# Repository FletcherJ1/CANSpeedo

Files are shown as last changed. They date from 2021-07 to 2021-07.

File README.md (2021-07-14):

# OBD Digital Speedometer
This project sparked from not having a digital speed readout on the dashboard of my car (Alfa Romeo Giulietta) when driving in 'Normal' and 'Dynamic' mode. This uses the OBD-II port to read the vehicle speed and then print the speed onto the radio message. This radio message is sent from the radio module to the dashboard and requires the 'Radio Repetition' setting in the dashboard to be enabled for the message to be displayed. This message is sent only when the car is on and is sent at a 2hz rate.

The end result of this is shown below while I was testing the display output:
<p align="center">
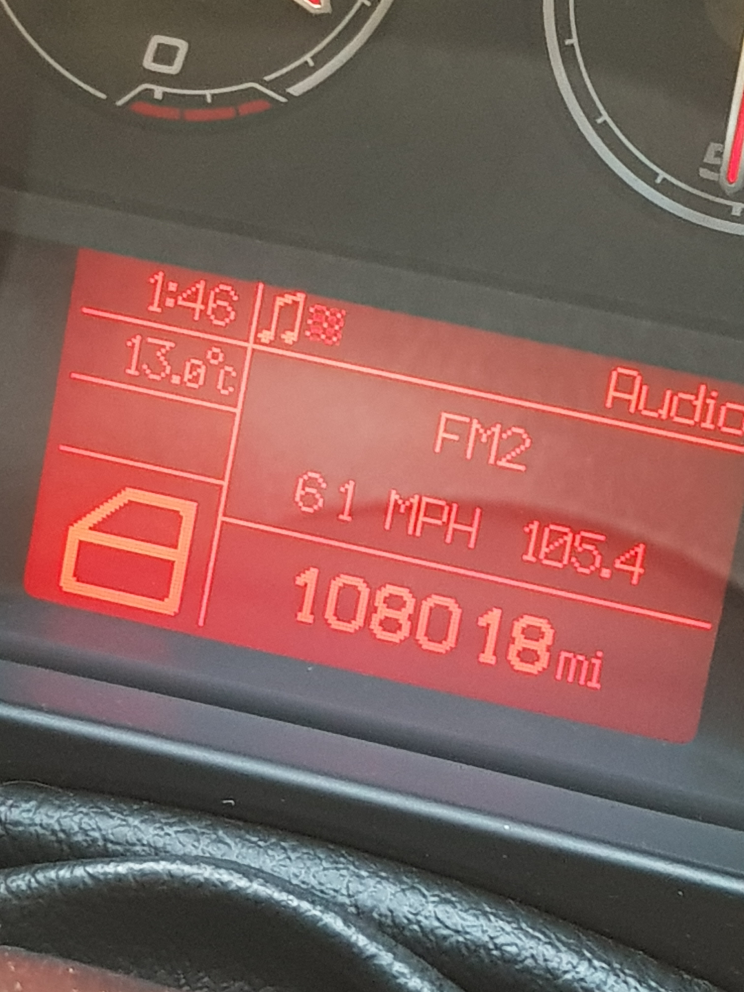
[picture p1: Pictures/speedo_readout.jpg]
    
</p>

## Vehicle information
The CAN network used is a 50Kbps network and is defined as the CAN-B network on the car (pins 1 and 9 on the OBD-2 port).

The car it has been tested on has 16" wheels and is a 2011 model. I'm not sure if the wheel diameter affects the speed value provided by CAN so the variable `SPEED_DIVIDER_MPH` might need to be changed to suit other vehicles and wheel diameters.

## Hardware
The hardware used is centered around an ATmega16M1 because it has an in-built CAN controller and works with the Arduino framework. It also helps keep the PCB as small as possible and keeps components count down.

There is a power switch for powering via either the car through the OBD port or via the ICSP header. This isn't really needed but added to make software development slightly easier.

The PCB is designed using Kicad 5.99 and is made to fit an [OBD-2 case](https://www.ebay.co.uk/itm/153652371926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) found on eBay.

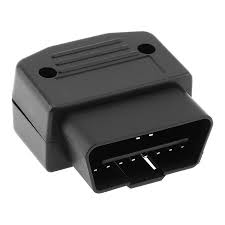
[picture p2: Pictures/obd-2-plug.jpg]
OBD-2 Plug Picture


The PCB is a 4 layer design because it didn't cost any more than a 2 layer design from JLCPCB.
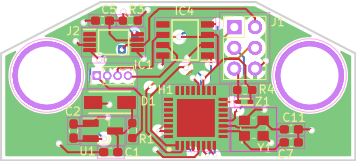
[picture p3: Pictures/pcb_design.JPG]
PCB Design

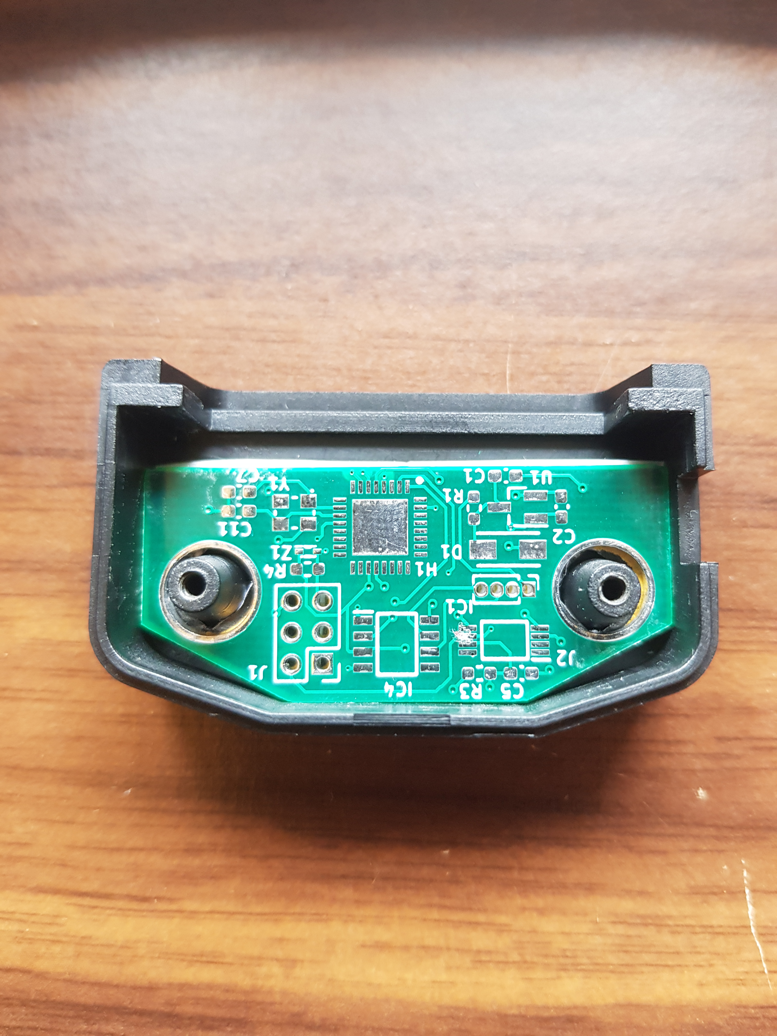
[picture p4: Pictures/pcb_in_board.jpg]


This fits in the car and still allows for the diagnostic panel to fit over the plug when it is plugged in.

## Data dumps
I've also included some data dumps (under the /Dumps folder) containing can information when the car is in various states. Feel free to use this information as desired to decode additional parts of the cars CAN data.

I also included a file in the dumps with additional information I found and some more decoded CAN messages. This might be confusing to read through but should give some ideas.

I found plotting the data with graphs, I used Flow CSV Viewer, quite helpful to find multi-byte variables as well as what the variable may represent based on how the data changes.

## Libraries Used
- [ATMegaxxM1-C1 Arduino IDE Support](https://github.com/thomasonw/ATmegaxxM1-C1)
- [ATMegaxxM1-C1 CAN Library](https://github.com/thomasonw/avr_can)

## Credits
- [FIAT Character Map](https://gist.github.com/fmntf/c4b2744bad3908ef10fc9a5d377f2823)

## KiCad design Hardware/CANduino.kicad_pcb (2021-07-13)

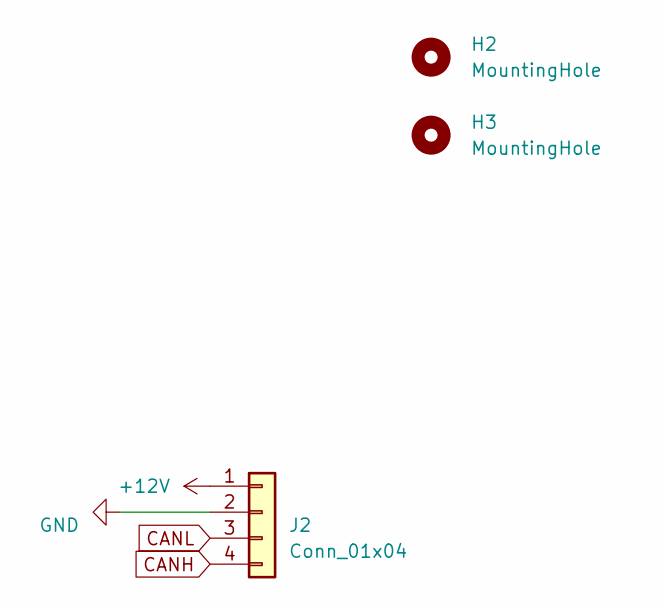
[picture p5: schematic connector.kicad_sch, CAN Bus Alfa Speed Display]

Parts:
H2, H3: MountingHole; MountingHole_6mm_Pad
J2: Conn_01x04; PinHeader_1x04_P1.27mm_Vertical

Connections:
+12V: J2.1; also elsewhere on the board
CANH: J2.4; also elsewhere on the board
CANL: J2.3; also elsewhere on the board
GND: J2.2; also elsewhere on the board

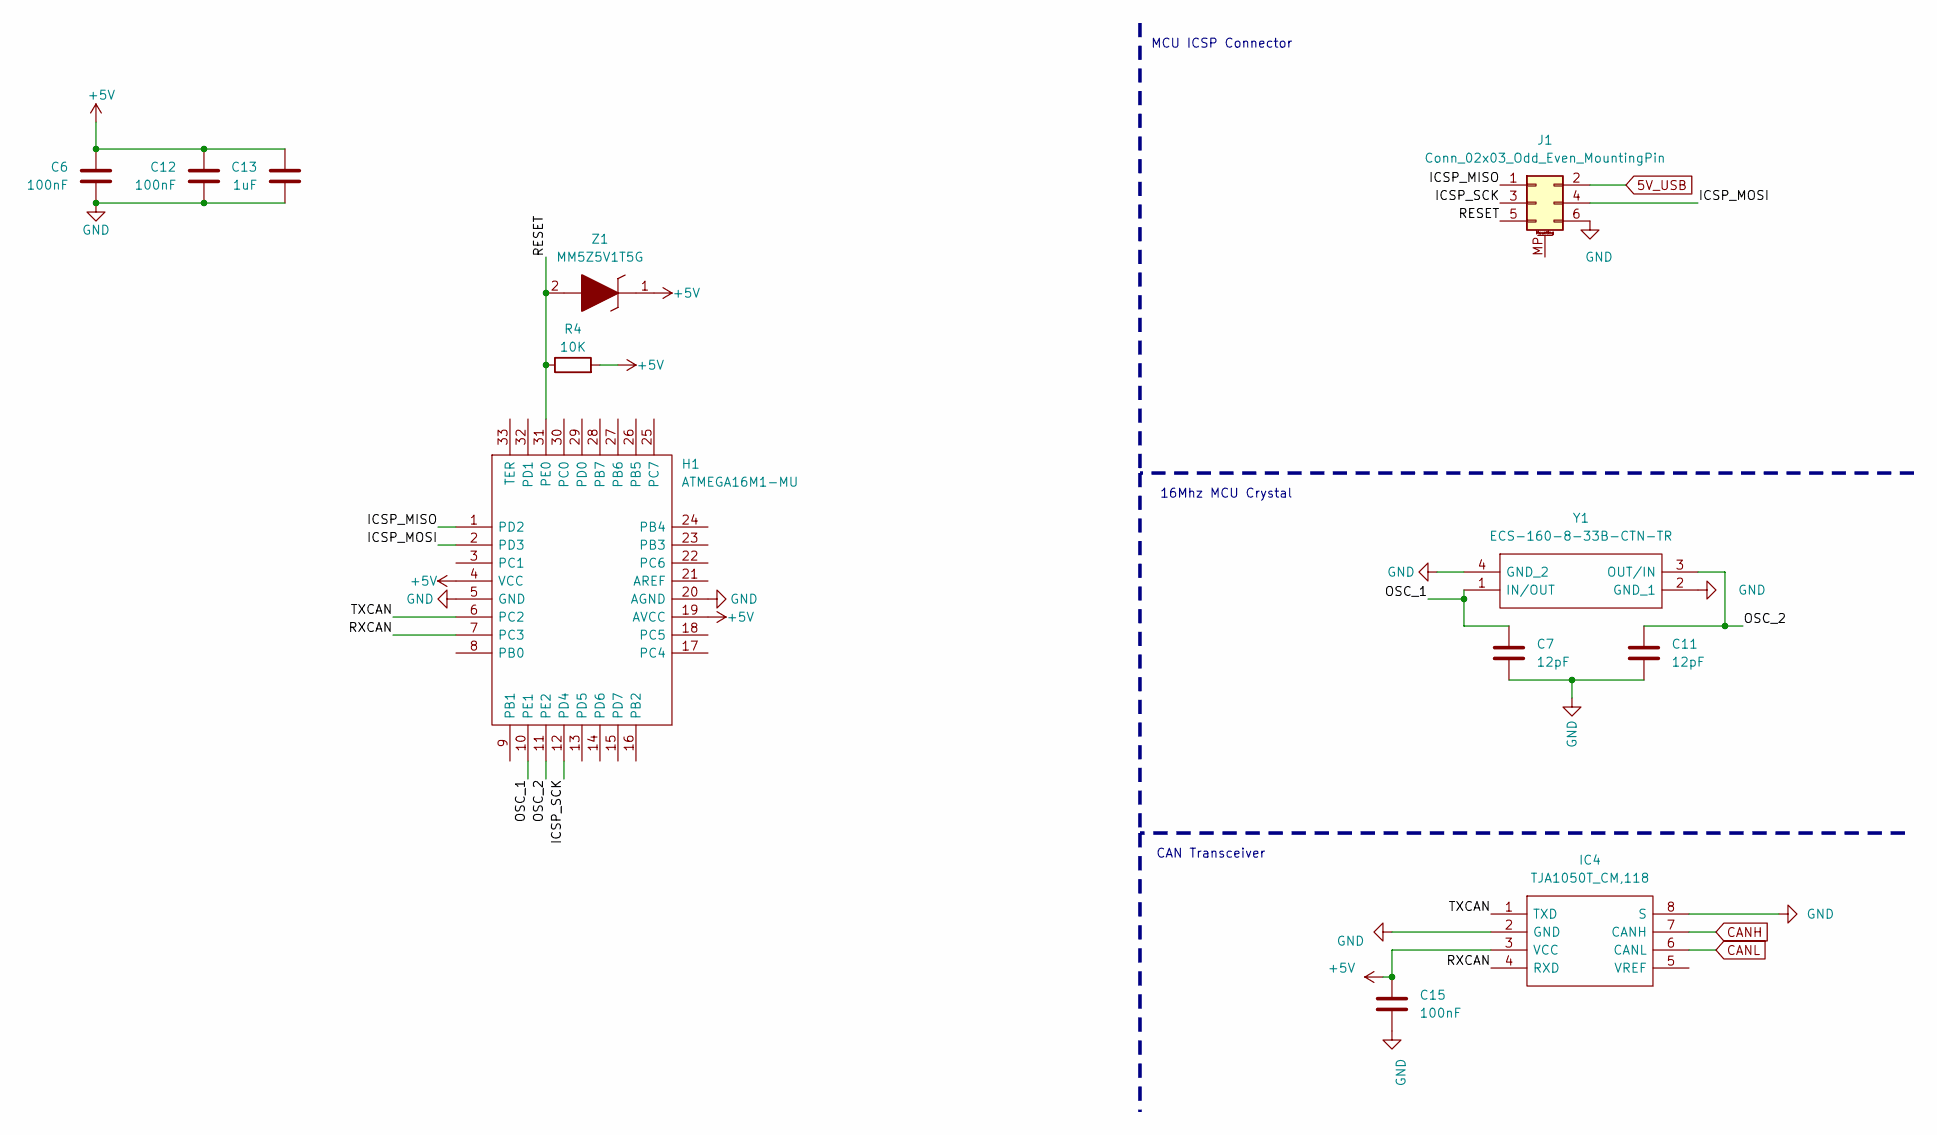
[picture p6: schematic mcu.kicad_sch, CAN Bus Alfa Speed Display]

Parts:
C6, C12, C15: 100nF; C_0603_1608Metric_Pad1.08x0.95mm_HandSolder
C7, C11: 12pF; C_0603_1608Metric_Pad1.08x0.95mm_HandSolder
C13: 1uF; C_0603_1608Metric_Pad1.08x0.95mm_HandSolder
H1: ATMEGA16M1-MU; QFN65P700X700X100-33N; Mouser Part Number 556-ATMEGA16M1-MU
IC4: TJA1050T_CM,118; SOIC127P600X175-8N; Mouser Part Number 771-TJA1050T/CM118
J1: Conn_02x03_Odd_Even_MountingPin; PinHeader_2x03_P2.54mm_Vertical
R4: 10K; R_0603_1608Metric_Pad0.98x0.95mm_HandSolder
Y1: ECS-160-8-33B-CTN-TR; ECS160833BCTNTR; Mouser Part Number 520-ECS160833BCTN-TR
Z1: MM5Z5V1T5G; SODFL1608X70N; Mouser Part Number 863-MM5Z5V1T5G

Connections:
5V_USB: J1.2; also elsewhere on the board
+5V: C6.2, C12.2, C13.2, C15.1, H1.4 (VCC), H1.19 (AVCC), IC4.3 (VCC), R4.2, Z1.1; also elsewhere on the board
/mcu/ICSP_MISO: H1.1 (PD2), J1.1
/mcu/ICSP_MOSI: H1.2 (PD3), J1.4
/mcu/ICSP_SCK: H1.12 (PD4), J1.3
/mcu/OSC_1: C7.1, H1.10 (PE1), Y1.1 (IN/OUT)
/mcu/OSC_2: C11.1, H1.11 (PE2), Y1.3 (OUT/IN)
/mcu/RESET: H1.31 (PE0), J1.5, R4.1, Z1.2
/mcu/RXCAN: H1.7 (PC3), IC4.4 (RXD)
/mcu/TXCAN: H1.6 (PC2), IC4.1 (TXD)
CANH: IC4.7 (CANH); also elsewhere on the board
CANL: IC4.6 (CANL); also elsewhere on the board
GND: C6.1, C7.2, C11.2, C12.1, C13.1, C15.2, H1.5 (GND), H1.20 (AGND), IC4.2 (GND), IC4.8 (S), J1.6, Y1.2 (GND_1), Y1.4 (GND_2); also elsewhere on the board

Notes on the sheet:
CAN Transceiver
MCU ICSP Connector
16Mhz MCU Crystal

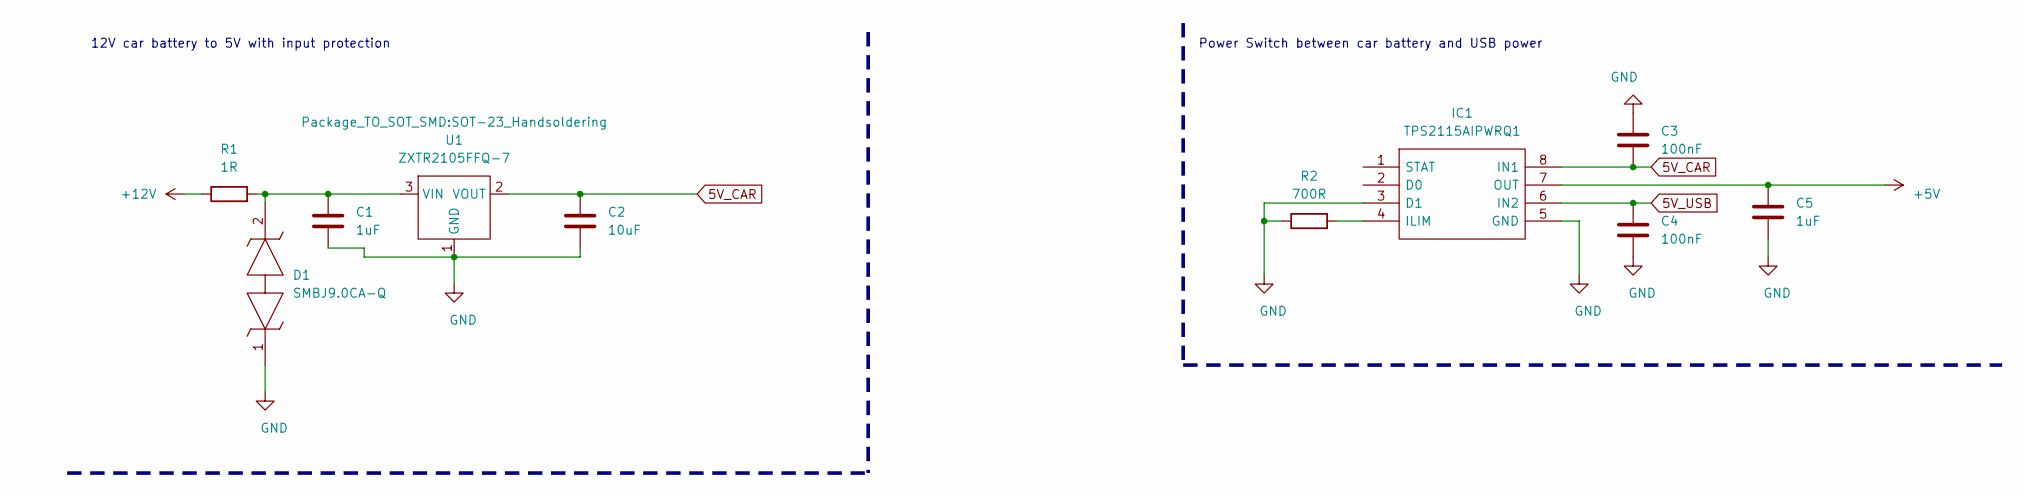
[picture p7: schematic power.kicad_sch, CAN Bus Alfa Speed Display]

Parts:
C1, C5: 1uF; C_0603_1608Metric_Pad1.08x0.95mm_HandSolder
C2: 10uF; C_0603_1608Metric_Pad1.08x0.95mm_HandSolder
C3, C4: 100nF; C_0603_1608Metric_Pad1.08x0.95mm_HandSolder
D1: SMBJ9.0CA-Q; DIONM5127X229N; Mouser Part Number 652-SMBJ9.0CA-Q
IC1: TPS2115AIPWRQ1; SOP65P640X120-8N; Mouser Part Number 595-TPS2115AIPWRQ1
R1: 1R; R_0603_1608Metric_Pad0.98x0.95mm_HandSolder
R2: 700R; R_0603_1608Metric_Pad0.98x0.95mm_HandSolder
U1: ZXTR2105FFQ-7; SOT-23_Handsoldering

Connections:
5V_CAR: C2.1, C3.2, IC1.8 (IN1), U1.2 (VOUT)
5V_USB: C4.1, IC1.6 (IN2); also elsewhere on the board
+5V: C5.1, IC1.7 (OUT); also elsewhere on the board
+12V: R1.1; also elsewhere on the board
GND: C1.2, C2.2, C3.1, C4.2, C5.2, D1.1, IC1.3 (D1), IC1.5 (GND), R2.1, U1.1 (GND); also elsewhere on the board
unnamed: C1.1, D1.2, R1.2, U1.3 (VIN)
unnamed: IC1.4 (ILIM), R2.2

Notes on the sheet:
12V car battery to 5V with input protection
Power Switch between car battery and USB power

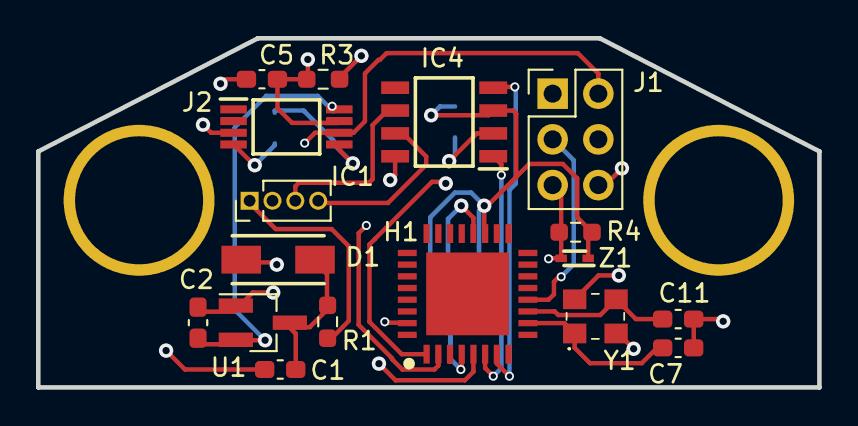
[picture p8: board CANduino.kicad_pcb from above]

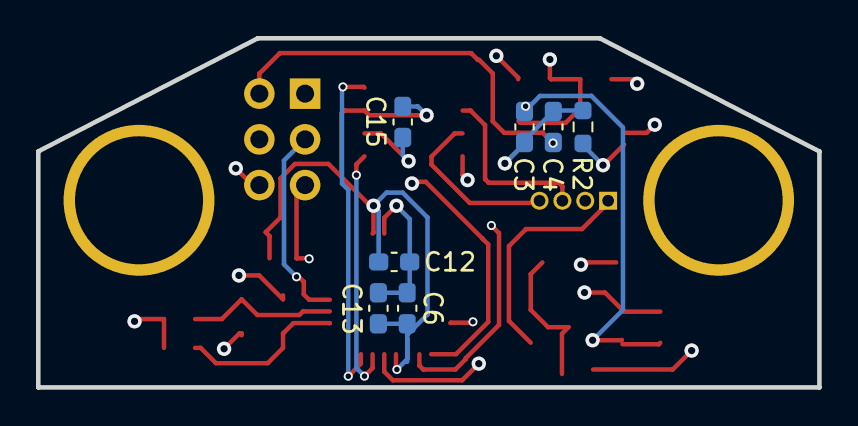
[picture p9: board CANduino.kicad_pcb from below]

Board: 4 copper layers, 43.4 x 19.4 mm, 26 parts (7 on the bottom side), 17 nets.

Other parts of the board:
R3: 50R; R_0603_1608Metric_Pad0.98x0.95mm_HandSolder

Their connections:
+5V: R3.1; also elsewhere on the board
GND: R3.2; also elsewhere on the board

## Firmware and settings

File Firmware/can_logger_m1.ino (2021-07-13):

#include <avr_can.h>
#include <avr/sleep.h>
#include <avr/power.h>

/*
 * Application: Alfa Romeo Giulietta OBD Dash Speedo
 * 
 * 
 * Description:
 *  Attaches to OBD-2 port and overwrites radio station name with speed in MPH at 2Hz rate.
 *  Requires 'Radio Repetition' to be ON in dashboard settings for this to work correctly.
 *  Dashboard update speed is slow enough that the time to overwrite station name isn't 
 *  noticable and doesn't cause flickering on display.
 * 
 * Requirements:
 *  - Car
 *  - OBD-II Diagnostics port (B-CAN network is used - pins 1/9)
 *  - Pinout for OBD-II: https://www.alfaobd.com/AlfaOBD_Android_Help.pdf
 * 
 *  
 * Credit:
 *  MCP2515 Library: https://github.com/autowp/arduino-mcp2515
 * 
 * Author: James Fletcher
 * Date: 25/04/2021
 */

#define SPEED_DIVIDER_MPH 23 // Found by trail/error and data-logging.

// Found by CAN bus sniffing
#define CAN_ID_RADIO_STATION 0x0A194005
#define CAN_ID_VEHICLE_SPEED 0x04394000

CAN_FRAME frame;

unsigned long lastPrint = 0;

uint16_t currentSpeed = 0;

bool halfSecond = false;

void setup() {
  // Disable unused peripherals to save power
  ADCSRA = 0;
  power_adc_disable();
  power_spi_disable();
  power_lin_disable();
  power_psc_disable();
  
  // Setup CAN stuff
  Can0.begin(CAN_BPS_50K);
  // 1 box for sending
  Can0.setNumTXBoxes(1);
  // 2 boxes for receiving with no filtering
  int filter;
  for (filter = 0; filter < 2; filter++) {
    Can0.setRXFilter(filter, 0, 0, true);
  }
  // consume remaining boxes.
  while (Can0.setRXFilter(0, 0, false) > 0);

  lastPrint = millis();
}

void send_speed_frame() {
 // Construct our own radio station name CAN frame
 CAN_FRAME frame;
 memset(&frame, 0, sizeof(frame));

 // Currently only supports 2 characters for number.
 uint16_t speed = currentSpeed;
 if (speed > 99) speed = 99;

 char tens = speed / 10;
 char digits = speed % 10;
 // char map has '0' char as value 1
 tens += 1;
 digits += 1;

 // Encoded as 'XX MPH' instead of radio message like 'ROCK FM'
 frame.id = CAN_ID_RADIO_STATION;
 frame.extended = true;
 frame.length = 8;
 // Put speed msg into the frame (0-9 only needs lower 4 bits of char map)
 frame.data.bytes[0] = (tens & 0xF) << 2;
 frame.data.bytes[1] = ( (digits & 0xF) << 4 ) | 0xA;
 // 'MPH' character encoding...
 frame.data.bytes[2] = 0x18;
 frame.data.bytes[3] = 0x6D;
 frame.data.bytes[4] = 0x30;
 frame.data.bytes[5] = 0;
 
 Can0.sendFrame(frame);
}

void loop() {
  CAN_FRAME incoming;
  
  if (Can0.rx_avail()) {
    
    if (Can0.read(incoming)) {
      if (incoming.id == CAN_ID_RADIO_STATION) {
        // send a frame inpersonating the radio station frame to update the 
        // speed of the vehicle, hides the radio frame. Done quickly to prevent flicker.
        send_speed_frame();
        lastPrint = millis();
        halfSecond = false;
      } else if (incoming.id == CAN_ID_VEHICLE_SPEED) { // Same data in ID: 0x84214006
        uint16_t speed = (incoming.data.bytes[0] << 8) + incoming.data.bytes[1];
        speed /= SPEED_DIVIDER_MPH; // Magic value to get to MPH.
        currentSpeed = speed;
      }
    }
  }
  
  // Print every half-second, 1 hz felt too slow.
  if (millis() - lastPrint > 500 && halfSecond == false) {
    halfSecond = true;
    send_speed_frame();
  }
}

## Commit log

2021-07-13 First commit - code and harware design provided
    [CANduino-B_Cu.gbr, CANduino-B_Mask.gbr, CANduino-B_Paste.gbr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]
2021-07-13 Removed backup files for Kicad
2021-07-13 Added picture of PCB design and updated README
2021-07-13 Added pictures of result and pcb in case
